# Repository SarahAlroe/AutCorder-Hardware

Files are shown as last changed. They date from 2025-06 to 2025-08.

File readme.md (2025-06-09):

Note: This is an early revision of the version 2 AutCorder hardware in testing. Works, but may not be ready for production. 

## Configuration jumpers 

- JP1 and JP2 provide options for enabling 3.3v on the last two pins of the FPC connector in either direction. This is for AF enabled OV5640 cameras. Untested, make sure pinout is correct. 

## Known issues 

- From V1 the replacement PDM microphone has tighter specifications, requiring a faster clock signal.

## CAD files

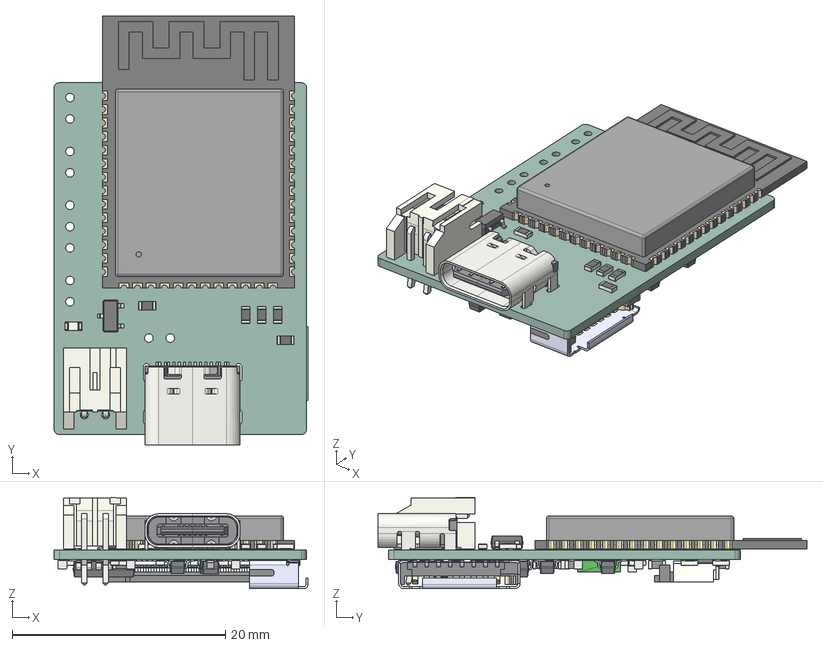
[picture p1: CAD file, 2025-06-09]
AutCorder-Hardware.step
23.8 x 40.2 x 8.58 mm
USB_C_Receptacle_GCT_USB4105-xx-A_16P_TopMnt_Horizontal
R_0603_1608Metric x 22
LED_0603_1608Metric x 2
SOT-23 x 3
JST_PH_S2B-PH-K_1x02_P2.00mm_Horizontal
ESP32-S3-WROOM-1
C_0603_1608Metric x 14
FFC2B35-24-G_REVA2
D_SOD-123
SOT-23-3 x 2
product0
product1
product2
product3
product4
product5
product6
product7
product8
10067099-200LF
SOT-23-5 x 2
AutCorder-Hardware_PCB

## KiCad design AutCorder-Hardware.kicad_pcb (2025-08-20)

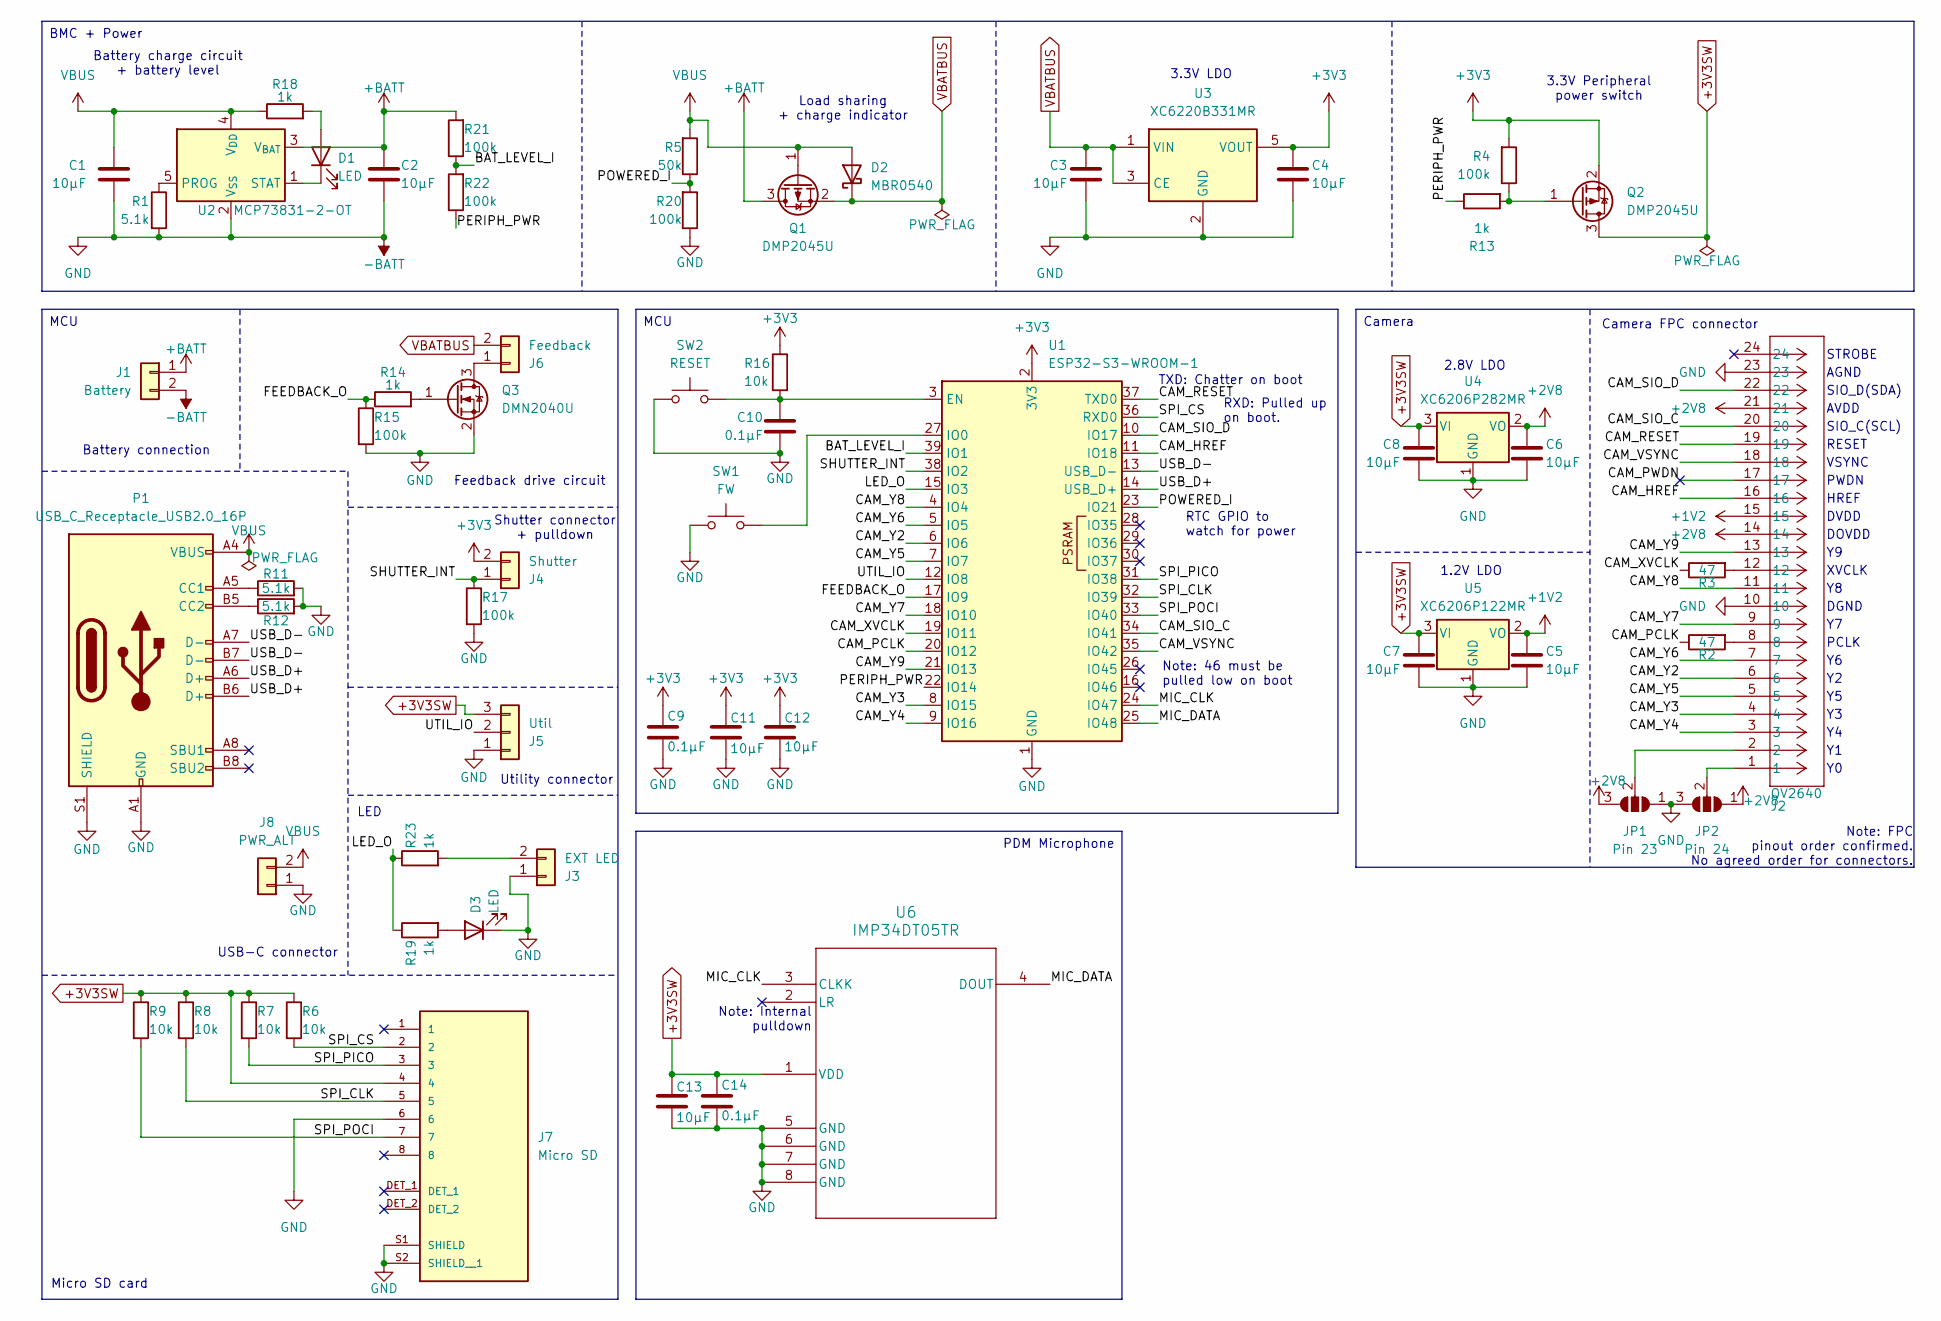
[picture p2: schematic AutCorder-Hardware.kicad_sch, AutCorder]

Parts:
C1, C2, C3, C4, C5, C6, C7, C8, C11, C12, C13: 10µF; C_0603_1608Metric
C9, C10, C14: 0.1µF; C_0603_1608Metric
D1, D3: LED; LED_0603_1608Metric
D2: MBR0540; D_SOD-123
J1: Battery; JST_PH_S2B-PH-K_1x02_P2.00mm_Horizontal
J2: OV2640; CONN_FFC2B35-24-x_GCT; PARTREV 1
J3: EXT LED; PinHeader_1x02_P2.00mm_Vertical
J4: Shutter; PinHeader_1x02_P2.00mm_Vertical
J5: Util; PinHeader_1x03_P2.00mm_Vertical
J6: Feedback; PinHeader_1x02_P2.00mm_Vertical
J7: Micro SD; AMPHENOL_10067099-200LF; PARTREV H
J8: PWR_ALT; PinHeader_1x02_P2.00mm_Vertical
JP1: Pin 23; SolderJumper-3_P0.75mm_Open_Pad0.5x1mm
JP2: Pin 24; SolderJumper-3_P0.75mm_Open_Pad0.5x1mm
P1: USB_C_Receptacle_USB2.0_16P; USB_C_Receptacle_GCT_USB4105-xx-A_16P_TopMnt_Horizontal
Q1, Q2: DMP2045U; SOT-23
Q3: DMN2040U; SOT-23
R1, R11, R12: 5.1k; R_0603_1608Metric
R2, R3: 47; R_0603_1608Metric
R4, R15, R17, R20, R21, R22: 100k; R_0603_1608Metric
R5: 50k; R_0603_1608Metric
R6, R7, R8, R9, R16: 10k; R_0603_1608Metric
R13, R14, R18, R19, R23: 1k; R_0603_1608Metric
SW1: FW; SW_EVP-AWED4A
SW2: RESET; SW_EVP-AWED4A
U1: ESP32-S3-WROOM-1
U2: MCP73831-2-OT; SOT-23-5
U3: XC6220B331MR; SOT-23-5
U4: XC6206P282MR; SOT-23-3
U5: XC6206P122MR; SOT-23-3
U6: IMP34DT05TR; HCLGA_3X4X1_STM

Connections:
+1V2: C5.1, J2.15, U5.2 (VO)
+2V8: C6.1, J2.14, J2.21, JP1.3 (B), JP2.1 (A), U4.2 (VO)
+3V3: C4.1, C9.1, C11.1, C12.1, J4.2, Q2.2 (S), R4.2, R16.1, U1.2 (3V3), U3.5 (VOUT)
+3V3SW: C7.1, C8.1, C13.1, C14.1, J5.3, J7.4, Q2.3 (D), R6.1, R7.1, R8.1, R9.1, U4.3 (VI), U5.3 (VI), U6.1 (VDD)
+BATT: C2.1, J1.1, Q1.3 (D), R21.2, U2.3 (V_{BAT})
-BATT: C1.2, C2.2, C3.2, C4.2, C5.2, C6.2, C7.2, C8.2, C9.2, C10.2, C11.2, C12.2, C13.2, C14.2, D3.1 (K), J1.2, J2.10, J2.23, J3.1, J5.1, J7.6, J7.S1 (SHIELD), J7.S2 (SHIELD__1), J8.1, JP1.1 (A), JP2.3 (B), P1.A1 (GND), P1.A12 (GND), P1.B1 (GND), P1.B12 (GND), P1.S1 (SHIELD), Q3.2 (S), R1.2, R11.2, R12.2, R15.2, R17.2, R20.1, SW1.1, SW2.1, U1.1 (GND), U1.40 (GND), U1.41 (GND), U2.2 (V_{SS}), U3.2 (GND), U4.1 (GND), U5.1 (GND), U6.5 (GND), U6.6 (GND), U6.7 (GND), U6.8 (GND)
/BAT_LEVEL_I: R21.1, R22.2, U1.39 (IO1)
/CAM_HREF: J2.16, U1.11 (IO18)
/CAM_PCLK: R2.1, U1.20 (IO12)
/CAM_PWDN: J2.17
/CAM_RESET: J2.19, U1.37 (TXD0)
/CAM_SIO_C: J2.20, U1.34 (IO41)
/CAM_SIO_D: J2.22, U1.10 (IO17)
/CAM_VSYNC: J2.18, U1.35 (IO42)
/CAM_XVCLK: R3.1, U1.19 (IO11)
/CAM_Y2: J2.6, U1.6 (IO6)
/CAM_Y3: J2.4, U1.8 (IO15)
/CAM_Y4: J2.3, U1.9 (IO16)
/CAM_Y5: J2.5, U1.7 (IO7)
/CAM_Y6: J2.7, U1.5 (IO5)
/CAM_Y7: J2.9, U1.18 (IO10)
/CAM_Y8: J2.11, U1.4 (IO4)
/CAM_Y9: J2.13, U1.21 (IO13)
/FEEDBACK_O: R14.1, R15.1, U1.17 (IO9)
/LED_O: R19.1, R23.1, U1.15 (IO3)
/MIC_CLK: U1.24 (IO47), U6.3 (CLKK)
/MIC_DATA: U1.25 (IO48), U6.4 (DOUT)
/PERIPH_PWR: R13.1, R22.1, U1.22 (IO14)
/POWERED_I: R5.1, R20.2, U1.23 (IO21)
/SHUTTER_INT: J4.1, R17.1, U1.38 (IO2)
/SPI_CLK: J7.5, R8.2, U1.32 (IO39)
/SPI_CS: J7.2, R6.2, U1.36 (RXD0)
/SPI_PICO: J7.3, R7.2, U1.31 (IO38)
/SPI_POCI: J7.7, R9.2, U1.33 (IO40)
/USB_D+: P1.A6 (D+), P1.B6 (D+), U1.14 (USB_D+)
/USB_D-: P1.A7 (D-), P1.B7 (D-), U1.13 (USB_D-)
/UTIL_IO: J5.2, U1.12 (IO8)
unnamed: D1.2 (A), R18.2
unnamed: D1.1 (K), U2.1 (STAT)
unnamed: D3.2 (A), R19.2
unnamed: J2.8, R2.2
unnamed: J2.12, R3.2
unnamed: J3.2, R23.2
unnamed: J6.1, Q3.3 (D)
unnamed: J2.2, JP1.2 (C)
unnamed: J2.1, JP2.2 (C)
unnamed: P1.A5 (CC1), R11.1
unnamed: P1.B5 (CC2), R12.1
unnamed: Q2.1 (G), R4.1, R13.2
unnamed: Q3.1 (G), R14.2
unnamed: C10.1, R16.2, SW2.2, U1.3 (EN)
unnamed: SW1.2, U1.27 (IO0)
unnamed: R1.1, U2.5 (PROG)
VBATBUS: C3.1, D2.1 (K), J6.2, Q1.2 (S), U3.1 (VIN), U3.3 (CE)
VBUS: C1.1, D2.2 (A), J8.2, P1.A4 (VBUS), P1.A9 (VBUS), P1.B4 (VBUS), P1.B9 (VBUS), Q1.1 (G), R5.2, R18.1, U2.4 (V_{DD})

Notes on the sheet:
Micro SD card
Shutter connector + pulldown
Utility connector
Note: FPC pinout order confirmed. No agreed order for connectors.
RXD: Pulled up on boot.
SIO_D(SDA)
VSYNC
Note: Internal pulldown
Load sharing + charge indicator
1.2V LDO
TXD: Chatter on boot
DVDD
3.3V Peripheral power switch
HREF
RTC GPIO to watch for power
Note: 46 must be pulled low on boot
LED
AGND
3.3V LDO
STROBE
USB-C connector
2.8V LDO
Feedback drive circuit
DOVDD
DGND
RESET
PCLK
Battery charge circuit + battery level
PWDN
Battery connection
XVCLK
SIO_C(SCL)
Camera FPC connector
AVDD
PDM Microphone
MCU
Camera
BMC + Power

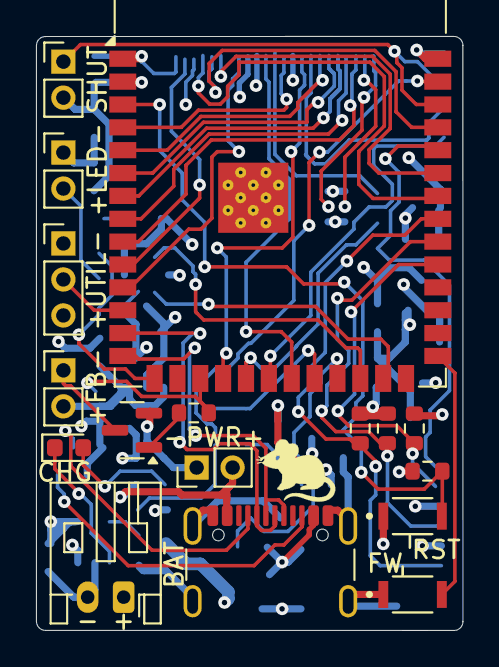
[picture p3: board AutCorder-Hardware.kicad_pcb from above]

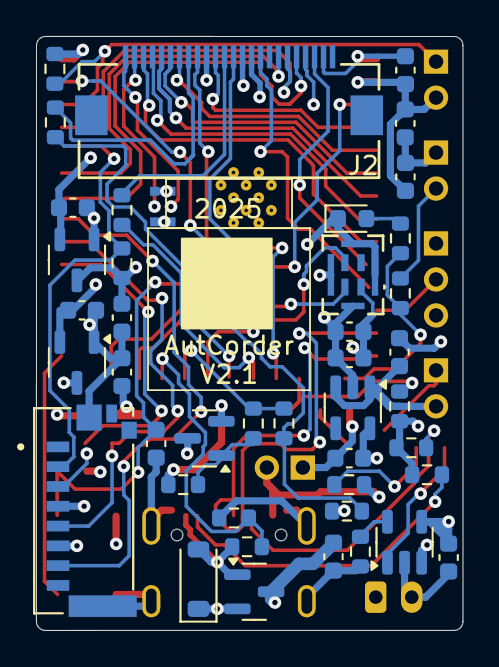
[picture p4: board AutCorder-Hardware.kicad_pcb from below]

Board: 4 copper layers, 23.7 x 33.0 mm, 61 parts (44 on the bottom side), 54 nets.

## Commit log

2024-11-05 V. 2.0
    [AutCorder-Hardware.kicad_pcb, AutCorder-Hardware.kicad_sch]
2024-11-05 V2 Minor changes
    [AutCorder-Hardware.kicad_pcb]
2025-01-08 Switched R5, Fixed USB data, Removed J3, Removed R10, Reoriented J1, Rearranged components.
    [AutCorder-Hardware.kicad_pcb, AutCorder-Hardware.kicad_sch]
2025-06-09 Switched to slimmer FPC connector. Rerouted.
    [AutCorder-Hardware.kicad_pcb, AutCorder-Hardware.kicad_sch, AutCorder-Hardware.step]
2025-08-20 Added interactive BOM. Updated KiCad.
    [AutCorder-Hardware.kicad_pcb, AutCorder-Hardware.kicad_sch]
